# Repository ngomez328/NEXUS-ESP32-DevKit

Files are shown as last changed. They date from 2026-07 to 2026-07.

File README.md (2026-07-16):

# NEXUS-ESP32-DevKit

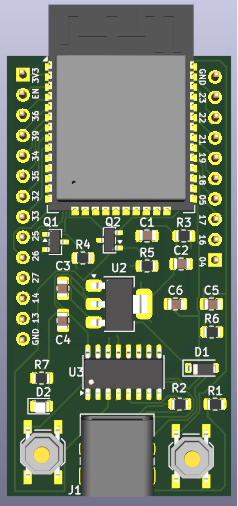
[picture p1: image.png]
Render 3D de la placa


Placa de desarrollo basada en el módulo **ESP32-WROOM-32E**, diseñada desde cero en **KiCad 10** como proyecto de ingeniería de hardware. El objetivo no fue copiar una placa existente, sino recorrer el flujo completo de diseño profesional —desde el esquemático hasta los archivos de fabricación— documentando y justificando cada decisión técnica.

## Características

- **Entrada USB-C** con resistencias pull-down de 5.1kΩ en CC1/CC2 para la negociación de corriente del estándar Type-C (sin ellas, un cargador USB-C no habilita VBUS)
- **Protección contra inversión de polaridad** mediante diodo Schottky en serie (SS14), elegido por su baja caída de voltaje (~0.3-0.5V) para preservar el margen de dropout del regulador
- **Regulación 5V → 3.3V** con LDO AMS1117-3.3 y capacitores de entrada/salida de 10µF según datasheet
- **USB-UART CH340C** configurado en modo 3.3V (V3 puenteado a VCC), eliminando la necesidad de conversión de niveles con el ESP32
- **Circuito de auto-reset** (DTR/RTS con dos transistores NPN 2N3904) para programación automática desde Arduino IDE / PlatformIO sin presionar botones
- **Botones físicos BOOT y RESET** como respaldo manual
- **LED indicador de encendido** (330Ω, calculado por Ley de Ohm para ~4mA)
- **24 GPIOs expuestos en headers** — únicamente pines seguros
- **PCB de 2 capas, 28 × 55 mm** (formato DevKit comercial), con plano de tierra completo en la capa inferior
- Serigrafía con **pinout etiquetado en ambas caras**

## Decisiones de diseño destacadas

**Selección de pines expuestos.** Se excluyeron deliberadamente de los headers: IO0 (en uso por el circuito de boot), IO1/IO3 (UART del CH340C), IO2/IO12/IO15 (pines de *strapping* que pueden impedir el arranque si reciben conexiones externas) y GPIO6-11 (flash SPI interna). El resultado: cualquier pin expuesto puede usarse sin riesgo de conflicto. Los pines IO34-IO39 están documentados como solo-entrada.

**Alimentación del CH340C.** El chip admite operación a 5V o 3.3V. Se eligió el modo 3.3V (puente V3-VCC) para que toda la lógica de la placa trabaje en un solo dominio de voltaje, simplificando el diseño y evitando conversiones de nivel en las líneas TX/RX.

**Plano de tierra.** En lugar de rutear GND como pistas individuales, se implementó una zona de cobre en B.Cu conectada mediante vías desde cada pad SMD. Se verificó la continuidad del plano reorganizando las pistas de la capa inferior para evitar islas aisladas.

**Reglas de diseño ajustadas a los footprints reales.** El pitch fino del conector USB-C y las vías térmicas del pad central del ESP32 requirieron ajustar el clearance mínimo a 0.15mm y el agujero pasante mínimo a 0.2mm — ambos dentro de las capacidades estándar de fabricantes como JLCPCB.

## Verificación

- **ERC (esquemático): 0 errores** — incluyendo resolución de PWR_FLAGs en redes de alimentación y exclusión documentada de la falsa alarma V3/VO del símbolo del CH340C
- **DRC (PCB): 0 errores** — con alivios térmicos reforzados en los pads GND del conector y márgenes al borde de placa respetados

## Estructura del repositorio

```
NEXUS-ESP32-DevKit/
├── NEXUS-ESP32-DevKit.kicad_pro    # Proyecto KiCad
├── NEXUS-ESP32-DevKit.kicad_sch    # Esquemático
├── NEXUS-ESP32-DevKit.kicad_pcb    # Layout de PCB
├── fabrication/                     # Gerbers y archivos de taladrado
├── images/                          # Renders 3D, esquemático, layout
└── README.md
```

## Galería

| Esquemático | Layout | Render 3D |
|---|---|---|
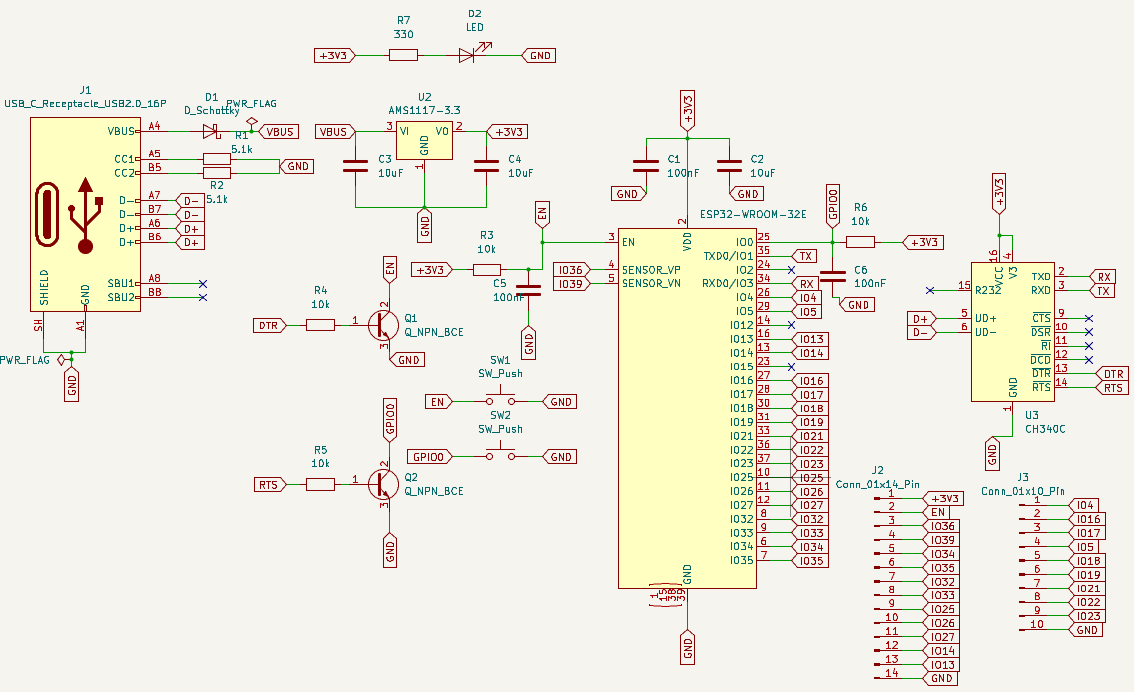
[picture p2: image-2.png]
Esquemático
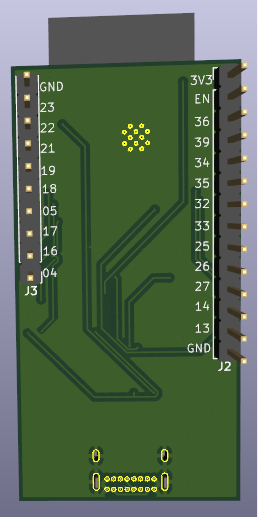
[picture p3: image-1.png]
3D
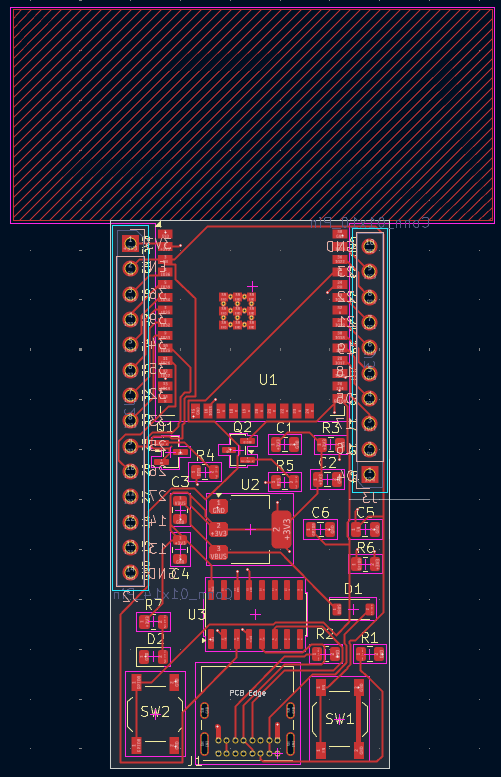
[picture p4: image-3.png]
Layout
|  |  |  |

## Herramientas

- **KiCad 10** — captura esquemática, layout, verificación ERC/DRC, generación de Gerbers
- **Git / GitHub** — control de versiones con historial de commits documentando cada bloque de diseño

## Estado del proyecto

✅ Esquemático completo y verificado
✅ Layout de PCB ruteado y verificado
✅ Archivos de fabricación generados
⬜ Fabricación y ensamblado (opcional, próxima etapa)
⬜ Firmware de prueba de periféricos (post-fabricación)

---

**Autor:** Nicolás Gómez — Ingeniero Electrónico
GitHub: [@ngomez328](https://github.com/ngomez328)

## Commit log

2026-07-08 Add .gitignore para KidCad
    Ignora los archivos temporales de KidCad, las copias de seguridad y las carpetas del historial
2026-07-09 Power supply schematic progress and cleanup
    [NEXUS-ESP32-DevKit.kicad_sch]
2026-07-09 Power input stage: USB-C, reverse protection, 3.3V regulation
    Completed the power input stage of the NEXUS-ESP32-DevKit:
    - USB-C receptacle (J1) with CC1/CC2 pull-down resistors (5.1k)
    for USB-PD/Type-C current advertisement, enabling VBUS detection
    - SBU1/SBU2 marked as No Connect (not used in this design)
    - Shield connected directly to GND (simple approach for v1)
    - Reverse polarity protection via Schottky diode (D1) in series
    with VBUS to minimize forward voltage drop
    - Voltage regulation from 5V to 3.3V using AMS1117-3.3 (U2) LDO
    - Input/output decoupling capacitors (C3, C4 - 10uF) per datasheet
    recommendations to ensure regulator stability
    - Schematic organized using global label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
    [NEXUS-ESP32-DevKit.kicad_sch]
2026-07-09 Etapa de alimentación: USB-C, protección, regulación a 3.3V
    Se completó la etapa de alimentación de entrada del NEXUS-ESP32-DevKit:
    - Conector USB-C (J1) con resistencias pull-down en CC1/CC2 (5.1k)
    para habilitar la negociación de corriente USB-C y detección de VBUS
    - SBU1/SBU2 marcados como No Connect (no se usan en este diseño)
    - Shield conectado directamente a GND (enfoque simple para v1)
    - Protección contra inversión de polaridad mediante diodo Schottky (D1)
    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
    [NEXUS-ESP32-DevKit.kicad_sch]
2026-07-09 Corrección de topología: capacitores de desacople C1/C2 del ESP32
    Se corrigió la conexión de los capacitores de desacople del ESP32:
    - Error inicial: C1 y C2 estaban conectados en serie entre +3V3 y VDD,
    quedando ambos extremos en el mismo nodo eléctrico (sin función de
    desacople real)
    - Corrección: +3V3 ahora conecta directo a VDD mediante una línea recta
    y continua; C1 (100nF) y C2 (10uF) se conectan como ramas independientes
    desde ese mismo nodo hacia GND
    - Esta topología permite que los capacitores cumplan su función real:
    dar un camino de baja impedancia hacia tierra para picos de corriente
    del ESP32, sin interrumpir el suministro principal de 3.3V
    Con esto, la e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
    [NEXUS-ESP32-DevKit.kicad_sch]
2026-07-10 Circuito USB-UART (CH340C) para programación del ESP32
    Se agregó el chip conversor USB-UART CH340C (U3) para permitir la
    programación y comunicación serial del ESP32 desde la PC:
    - CH340C configurado en modo 3.3V: VCC y V3 puenteados al mismo riel
    +3V3, evitando usar el regulador interno de 5V a 3.3V del propio chip
    - Líneas D+/D- del conector USB-C (J1) unificadas correctamente entre
    sus pines duplicados (A6/B6 y A7/B7), garantizando funcionamiento
    sin importar la orientación del cable USB-C
    - Cruce TX/RX entre el CH340C y el ESP32: TXD0/IO1 del ESP32 conectado
    a RXD del CH340C, y RXD0/IO3 del ESP32 conectado a TXD del CH340C
    [NEXUS-ESP32-DevKit.kicad_sch]
2026-07-10 Circuito de auto-reset (DTR/RTS) para programacion automatica
    Se completó el circuito de auto-reset del ESP32, permitiendo programar
    la placa desde el IDE sin presionar botones físicos:
    - Q1 (2N3904/NPN): controla el pin EN, con base conectada a DTR
    (via R4, 10k) y colector a la red EN existente
    - Q2 (2N3904/NPN): controla el pin GPIO0/Boot, con base conectada
    a RTS (via R5, 10k) y colector a la red GPIO0
    - Nuevo pull-up en GPIO0 (R6, 10k a +3V3) con capacitor de filtrado
    (C6, 100nF), replicando la misma lógica ya usada en EN
    - Las señales DTR/RTS del CH340C, manejadas automáticamente por el
    IDE al programar, controlan los transistores para generar la
    secuencia correcta de re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
    [NEXUS-ESP32-DevKit.kicad_sch]
2026-07-10 Botones fisicos BOOT y RESET (respaldo manual)
    Se agregaron los botones físicos de respaldo para reset y modo bootloader:
    - SW1 (RESET): conectado entre la red EN y GND. Al presionarlo, fuerza
    EN a LOW momentáneamente, reiniciando el ESP32. Aprovecha el pull-up
    existente (R3) para volver a HIGH al soltar
    - SW2 (BOOT): conectado entre la red GPIO0 y GND. Al presionarlo (junto
    con RESET), fuerza al ESP32 a entrar en modo bootloader manual.
    Aprovecha el pull-up existente (R6)
    Estos botones son un respaldo manual independiente del circuito de
    auto-reset (DTR/RTS), siguiendo el estándar de las placas de desarrollo
    comerciales.
    [NEXUS-ESP32-DevKit.kicad_sch]
2026-07-10 LED indicador de encendido (power LED)
    - Resistencia limitadora R7 (330 ohm), calculada con Ley de Ohm:
    R = (3.3V - VF_led) / I_deseada = (3.3V - 2V) / 5mA ≈ 260 ohm,
    redondeado al valor comercial estándar de 330 ohm (~4mA de corriente,
    adecuado para uso como indicador visual)
    - LED (D2) conectado entre R7 y GND, ánodo del lado de +3V3/R7,
    cátodo hacia GND
    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
    [NEXUS-ESP32-DevKit.kicad_sch]
2026-07-10 Headers de expansion GPIO (J2, J3) - pines seguros unicamente
    Se agregaron los headers de expansión para exponer los GPIOs del
    ESP32-WROOM-32E disponibles para uso general:
    - J2 (Conn_01x14, header izquierdo): +3V3, EN, IO36, IO39, IO34, IO35,
    IO32, IO33, IO25, IO26, IO27, IO14, IO13, GND
    - J3 (Conn_01x10, header derecho): IO4, IO16, IO17, IO5, IO18, IO19,
    IO21, IO22, IO23, GND
    Criterio de diseño: se excluyeron deliberadamente de los headers los
    siguientes pines para evitar cualquier conflicto o riesgo de arranque:
    - IO0 (Boot): en uso por el circuito de auto-reset (Q2/SW2)
    - IO1 (TX0) / IO3 (RX0): en uso permanente por el CH340C (USB-UART)
    - IO2, IO12, IO15: pines de "strapping", pu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
    [NEXUS-ESP32-DevKit.kicad_sch]
2026-07-10 Correccion de ERC: PWR_FLAG en redes GND y +3V3, limpieza de pines
    e ejecutó el ERC (Electrical Rules Checker) sobre el esquemático
    completo y se corrigieron todas las infracciones encontradas:
    - Se marcaron como No Connect los pines de strapping no expuestos
    (IO2, IO12, IO15) y los pines no utilizados del CH340C
    (R232, CTS, DSR, RI, DCD)
    - Se agregó PWR_FLAG en la red +3V3 (salida del AMS1117 vía diodo D1)
    para confirmar la fuente de alimentación ante el ERC
    - Se agregó PWR_FLAG en la red GND general, resolviendo errores de
    "pin de entrada de alimentación no conectado" en los pines GND del
    ESP32 (U1) y del regulador AMS1117 (U2). Este error ocurría porque
    el ERC requier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
    [NEXUS-ESP32-DevKit.kicad_sch]
2026-07-10 Colocacion de componentes en PCB y configuracion de clases de red
    Se avanzó en la etapa de layout de PCB del NEXUS-ESP32-DevKit:
    - Se asignaron footprints a los 25 componentes del esquemático
    (resistencias y capacitores en 0805, diodos en SOD-123, LED en
    0805, transistores en SOT-23, headers de 2.54mm, botones táctiles SMD)
    - Se definió el contorno físico de la placa (Edge.Cuts) con dimensiones
    28mm x 55mm, replicando las proporciones de una DevKit ESP32 comercial
    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
    [NEXUS-ESP32-DevKit.kicad_pcb, NEXUS-ESP32-DevKit.kicad_sch]
2026-07-14 Ruteo de senales y plano de tierra en B.Cu (pendiente vias de GND)
    Avance en el ruteo del PCB del NEXUS-ESP32-DevKit:
    - Se rutearon todas las señales de datos y alimentación en F.Cu:
    USB D+/D- (unificando pines duplicados A6/B6 y A7/B7 del conector
    USB-C), señales CC1/CC2, alimentación VBUS/+3V3, UART (TX/RX),
    auto-reset (DTR/RTS), y todas las conexiones a headers GPIO
    - Se resolvieron zonas de alta congestión alrededor del conector
    USB-C mediante reducción puntual de ancho de pista y uso de vías
    para escape por la capa inferior
    - Se creó el plano de tierra (zona de relleno) en la capa B.Cu,
    asignado a la red GND, cubriendo toda el área de la placa
    Pendiente: colocar l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
    [NEXUS-ESP32-DevKit.kicad_pcb]
2026-07-16 Layout de PCB completo y verificado: DRC sin errores. Correccion de orientacion de headers J2/J3 (flip a cara inferior)
    Se completó el ruteo y la verificación final del PCB del NEXUS-ESP32-DevKit:
    - Vías de conexión a plano de tierra colocadas para todos los pads GND
    de componentes SMD (los pads THT de headers y conector conectan
    directamente al atravesar ambas capas)
    - Plano de tierra (B.Cu) verificado y continuo tras reorganización
    de pistas
    - Ajustes en reglas de diseño para compatibilidad con los footprints
    reales: margen mínimo reducido a 0.15mm (pitch fino del conector
    USB-C) y agujero pasante mínimo a 0.2mm (vías térmicas del pad
    central del ESP32-WROOM-32E) —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
    [NEXUS-ESP32-DevKit.kicad_pcb]
2026-07-16 Serigrafia: etiquetado de pinout en ambas caras
    Se agregó el etiquetado de pines (pinout) de los headers J2 y J3 en
    la serigrafía, en ambas caras de la placa (F.Silkscreen y B.Silkscreen):
    - Cara superior: legible con la placa montada en protoboard
    - Cara inferior: legible al inspeccionar la placa por debajo
    - Tamaño de texto 0.7mm con grosor 0.12mm, dentro de los límites
    de fabricación estándar para serigrafía legible
    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
    [NEXUS-ESP32-DevKit.kicad_pcb]
2026-07-16 Archivos de fabricacion: Gerbers y drill files
    Se generaron los archivos de fabricación del NEXUS-ESP32-DevKit:
    - Gerbers de todas las capas: F.Cu, B.Cu, F.Silkscreen, B.Silkscreen,
    F.Mask, B.Mask y Edge.Cuts
    - Archivos de taladrado (drill files) para vías y pads THT
    - Organizados en carpeta dedicada dentro del proyecto
    Con estos archivos la placa queda lista para ser enviada a fabricar
    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
    [NEXUS-ESP32-DevKit-B_Cu.gbr, NEXUS-ESP32-DevKit-B_Mask.gbr, NEXUS-ESP32-DevKit-B_Silkscreen.gbr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]
2026-07-16 Documentacion: README del proyecto con galeria de imagenes
    Se agregó la documentación final del proyecto:
    - README completo con descripción, características, decisiones de
    diseño justificadas, estado de verificación (ERC/DRC), estructura
    del repositorio y galería
    - Imágenes: renders 3D (ambas caras), esquemático completo y layout
    de PCB
    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
2026-07-16 Correccion README
    Correcion de dos de las imagens del README
